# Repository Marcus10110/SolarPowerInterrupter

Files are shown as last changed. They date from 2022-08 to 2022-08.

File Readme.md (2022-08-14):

# Solar Power Interrupter PCB

## Purpose

We will be charging the camp battery from both solar and generators. However, we do not want to attempt to charge the battery from two source at once, since they are unable to cooperate.
To avoid this situation, the solar charger should automatically be disengaged when the generator is turned on.
The solar charger connection instructions says to connect the battery before the solar panels. Therefore to turn off the solar charger, we should disconnect the panels from the solar charger.

This connection is approximately a maximum of 100V and 12A, DC.

The generator is detected by the presence of 5V from a USB charger connected to the generator.

When the 5V is not present, the relay should be conducting. The current required to turn on the relay will be provided by the battery.

The solar power interrupter will effectively logically invert the input from the USB charger, and switch on/off the relay using the battery voltage and a high side switch.

## Parts:

- P-channel MOSFET: BSS84
- N-channel MOSFET: BSS138

## Features:

- Input RC filter in case the USB-C input flickers on and off while the generator starts or stops.
- Polyfuse on USB input
- Polyfuse on battery input

## Review Points:

- Check Vgs and Vds absolute maximums, must survive max battery voltage (25V)
  - Vgs out of range on both!:
    - Fix: add voltage dividers. [Done]
- Check that the pin numbering in the schematic, PCB, and data sheet are consistent.
- Check relay behavior - do I need a current limiting resistor on the input? should one be added anyway for safety?
- Verify USB-C connector CC connections.
- Verify PCB silk screen matches connections.
- Is the battery safe from all failures?
- Is the 5V USB supply safe from all failures?
- All parts have part numbers!

# Images

Note, some small changes have been made since these images were captured.
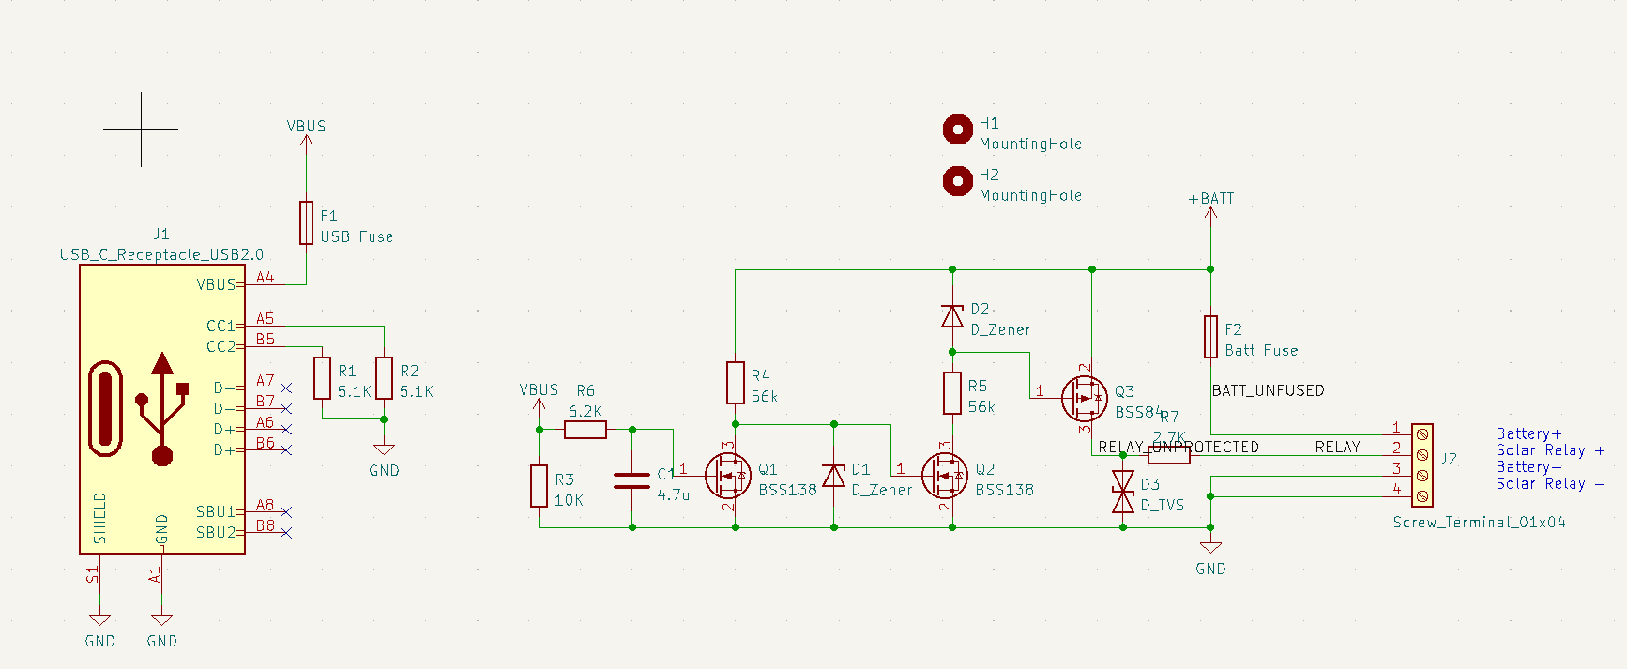
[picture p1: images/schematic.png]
Schematic

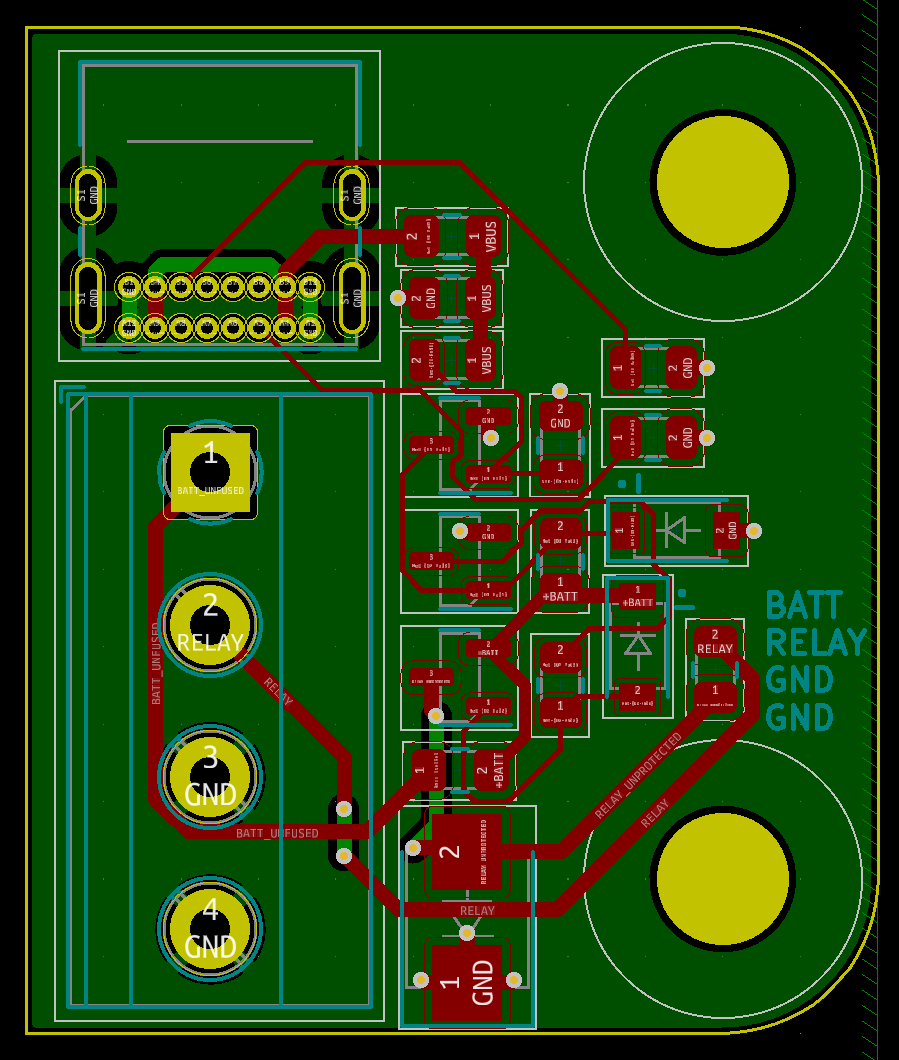
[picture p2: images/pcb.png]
PCB

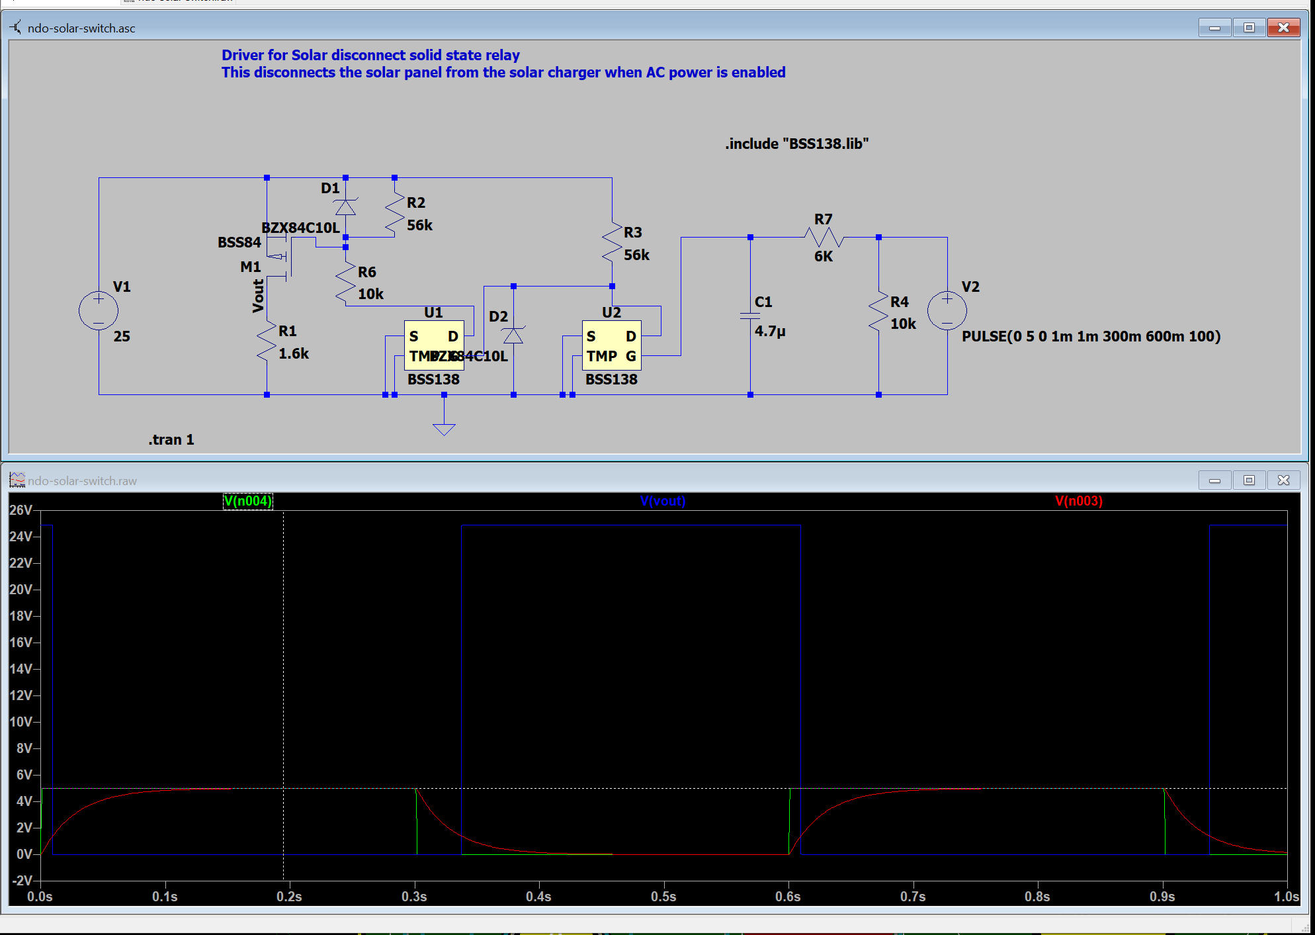
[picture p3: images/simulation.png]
Simulation


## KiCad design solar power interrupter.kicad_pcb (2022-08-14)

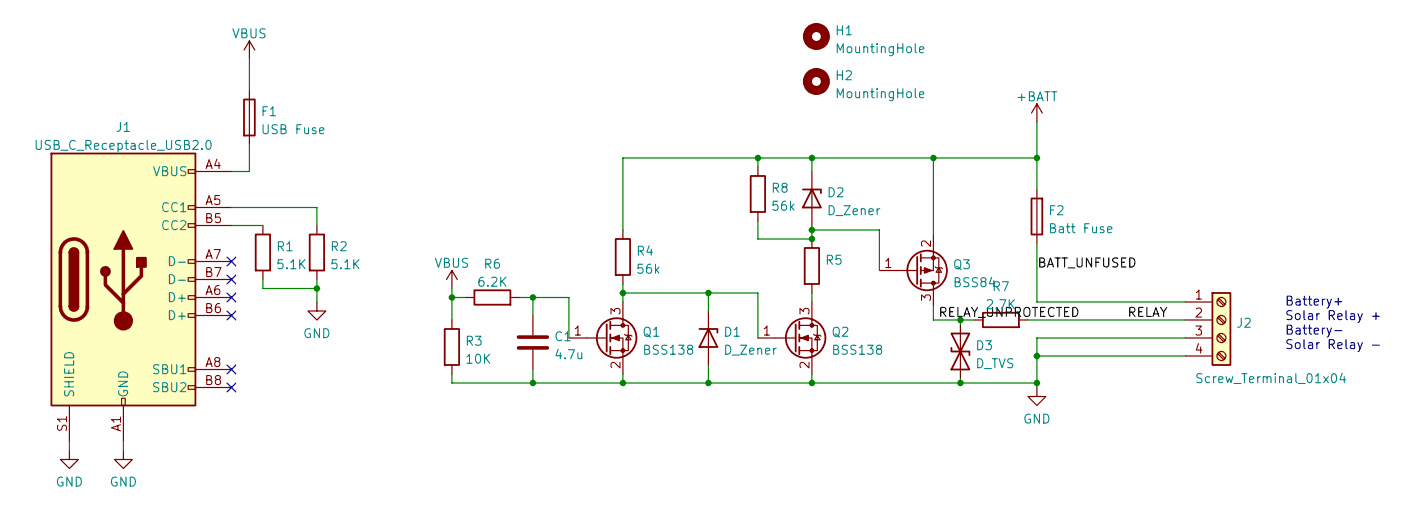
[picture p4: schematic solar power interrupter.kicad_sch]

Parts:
C1: 4.7u; C_0805_2012Metric
D1, D2: D_Zener; D_SOD-123
D3: D_TVS; D_SMB
F1: USB Fuse; Fuse_0805_2012Metric_Pad1.15x1.40mm_HandSolder
F2: Batt Fuse; Fuse_0805_2012Metric_Pad1.15x1.40mm_HandSolder
H1, H2: MountingHole; MountingHole_4.3mm_M4
J1: USB_C_Receptacle_USB2.0; USB_C_Receptacle_GCT_USB4085
J2: Screw_Terminal_01x04; TerminalBlock_Phoenix_MKDS-1,5-4_1x04_P5.00mm_Horizontal
Q1, Q2: BSS138; SOT-23
Q3: BSS84; SOT-23
R1, R2: 5.1K; R_0805_2012Metric
R3: 10K; R_0805_2012Metric
R4, R8: 56k; R_0805_2012Metric
R5: (no value)
R6: 6.2K; R_0805_2012Metric
R7: 2.7K; R_0805_2012Metric

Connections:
+BATT: D2.1 (K), F2.2, Q3.2 (S), R4.1, R8.1
/BATT_UNFUSED: F2.1, J2.1
/RELAY: J2.2, R7.2
/RELAY_UNPROTECTED: D3.2 (A2), Q3.3 (D), R7.1
GND: C1.2, D1.2 (A), D3.1 (A1), J1.A1 (GND), J1.A12 (GND), J1.B1 (GND), J1.B12 (GND), J1.S1 (SHIELD), J2.3, J2.4, Q1.2 (S), Q2.2 (S), R1.2, R2.2, R3.2
unnamed: C1.1, Q1.1 (G), R6.2
unnamed: D1.1 (K), Q1.3 (D), Q2.1 (G), R4.2
unnamed: D2.2 (A), Q3.1 (G), R5.1, R8.2
unnamed: F1.2, J1.A4 (VBUS), J1.A9 (VBUS), J1.B4 (VBUS), J1.B9 (VBUS)
unnamed: J1.A5 (CC1), R2.1
unnamed: J1.B5 (CC2), R1.1
unnamed: Q2.3 (D), R5.2
VBUS: F1.1, R3.1, R6.1

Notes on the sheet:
Battery+ Solar Relay + Battery- Solar Relay -

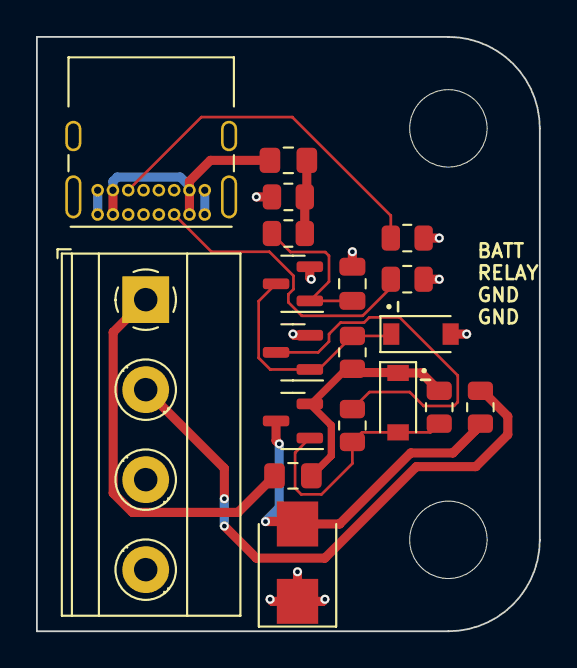
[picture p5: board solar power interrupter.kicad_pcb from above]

Board: 2 copper layers, 27.9 x 33.0 mm, 21 parts (0 on the bottom side), 13 nets.

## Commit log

2022-08-09 added KiCad project, LTSpice simulation, and git ignore.
    [solar power interrupter.kicad_pcb, solar power interrupter.kicad_sch]
2022-08-14 added protection to battery connection, changed pins on connector for safety, added zener diodes to limit Vgs, added protection for relay drive pin
    [solar power interrupter.kicad_pcb, solar power interrupter.kicad_sch]
2022-08-14 updated simulation added needed pullup resistor, note this wasn't included in the PCB that I ordered. added images to readme.
    [solar power interrupter.kicad_pcb, solar power interrupter.kicad_sch]
